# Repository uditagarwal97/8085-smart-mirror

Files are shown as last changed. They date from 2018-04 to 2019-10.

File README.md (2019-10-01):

View this project on [CADLAB.io](https://cadlab.io/node/885). 

# 8085-smart-mirror
Open source project which aims at making a smart mirror using Intel 8085 with esp8266 as wifi interface.

# Project Abstract
Our smart mirror won’t just say you’re the prettiest of them all. It will also tell you the temperature, daily tasks(to-do list), weather outside, upcoming calendar appointments, and more. Encapsulated within a wooden frame, it will consist of a two-way mirror with an electronic display and wifi module behind the mirror. In form of widgets, it deploys various multi-colour LED's accompanied with stencils to form an iconic indicator for various weather conditions.

An essential part of modern interior designing ideas is the use of mirrors. Long gong are the days, when mirror is just used to see your face. Now, Mirrors being an integral part of every household are now used to provide glamorous user-interface for a variety of smart products. Our project, 8085 based smart mirror is an attempt to intermingle our modern luxury with a so called 'obsolete' Intel's microprocessor 8085. 

Main objective of our work is to keep the user updated with his To-Do list, which was once entered by the user, stored securely on a reliable cloud database. With our Smart Mirror android application interface, user can smoothly update the data, with his location (required for weather) along with the SSID and password of the wireless interface, being used for data exchange purpose.
Along with this, weather forecast along with temperature is displayed for user's convenience.

Please find the project related documenttaion files in the docs directory and the associated YouTube video can be found [here](https://www.youtube.com/watch?v=hadKsCXobCI).

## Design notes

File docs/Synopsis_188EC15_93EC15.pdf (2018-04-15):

# 8085 based Smart Mirror

### Manoj sahu 93EC15 Udit kumar agarwal 188EC15

### Feb 2, 2018

## Synopsis

Our smart mirror wont just say youre the prettiest of them all. It will also tell you the time, daily tasks(to-do list), weather outside, upcoming calendar appointments, and more. Encapsulated within a wooden frame, it will consist of a two-way mirror with an electronic display and wifi module behind the mirror. In form of widgets, it deploys various multi-colour leds accompanied with stencils to form an iconic indicator for various weather conditions, pollution level etc. Along with it, there will be a 4 digit SSD which can be used to display time as well as temperature(in both centigrade and Fahrenheit format), in close proximity of user.

Keywords: 8085, Microprocessor, Assembly language, Two way mirror, esp8266

Category: Application based project

## 1. Motivation

Designing a micro processor 1 based system does involves thorough knowledge of prim-

itive yet pedagogically important computer architectures. Designing a complete embedded hardware project right from scratch imparts basic knowledge of advanced digital blocks used today in various micro controllers. Our project Smart mirror, presents an enthralling blend of science fiction with reality.

## 2. Justification

Nowadays, implementation of smart mirrors includes using high end processors like in raspberry pi and other single board computers. Using a cheap microprocessor like 8085 for recreating smart mirror, justifies it’s processing power. Moreover, Mirrors are an essential parts of every room, using it to display important information along with To-Do list sounds to be an interesting and a useful idea.

## 3. Brief description

It deploys a two way mirror to display multitude of necessary information in close proximity of user. Information to be displayed can be manipulated via an android application using wifi interface.

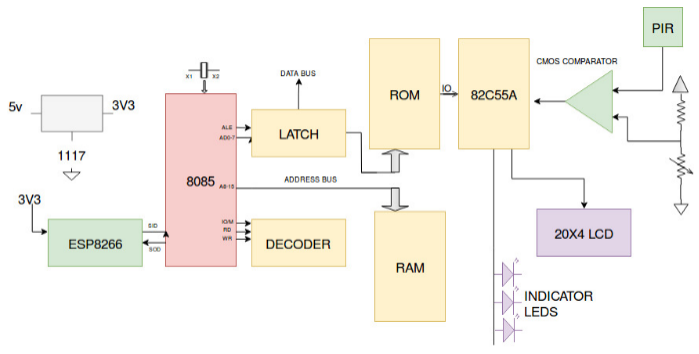
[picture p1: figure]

1here, Intel 8085

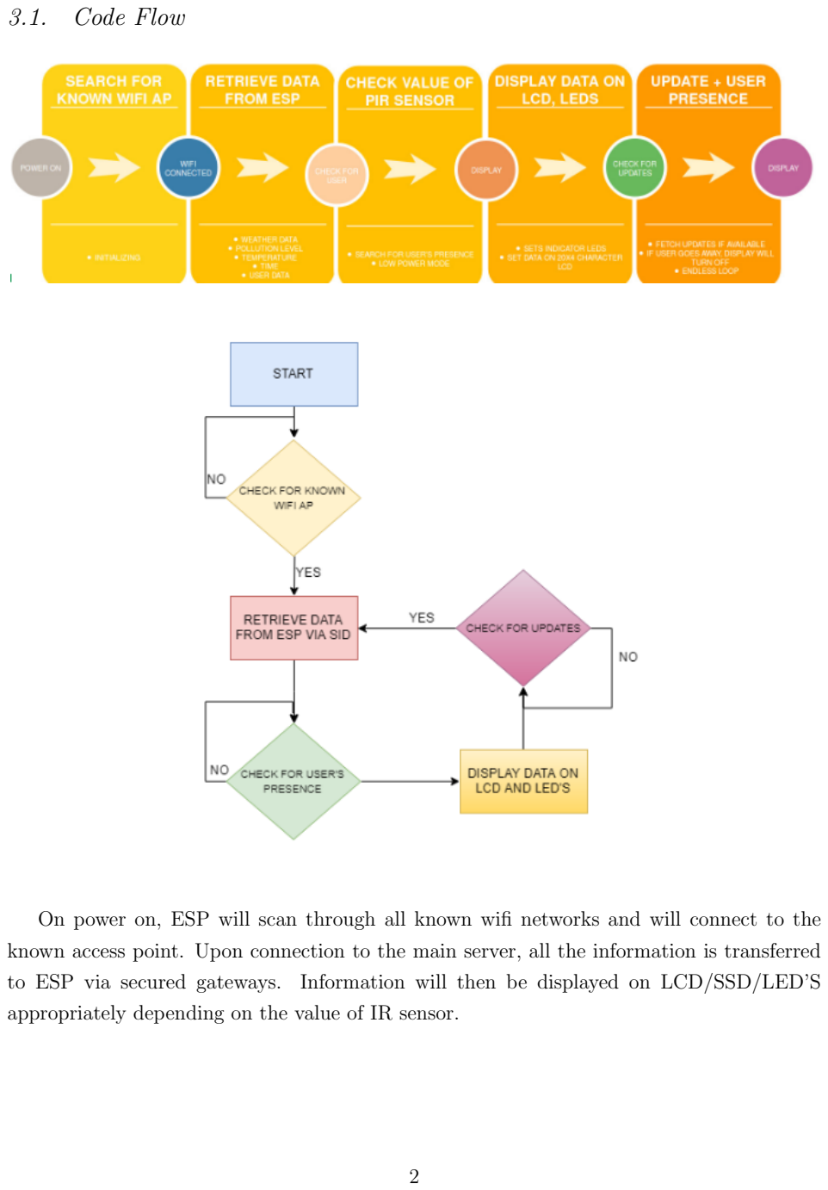
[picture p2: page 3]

### 3.1. Code Flow

On power on, ESP will scan through all known wifi networks and will connect to the known access point. Upon connection to the main server, all the information is transferred to ESP via secured gateways. Information will then be displayed on LCD/SSD/LED’S

appropriately depending on the value of IR sensor.

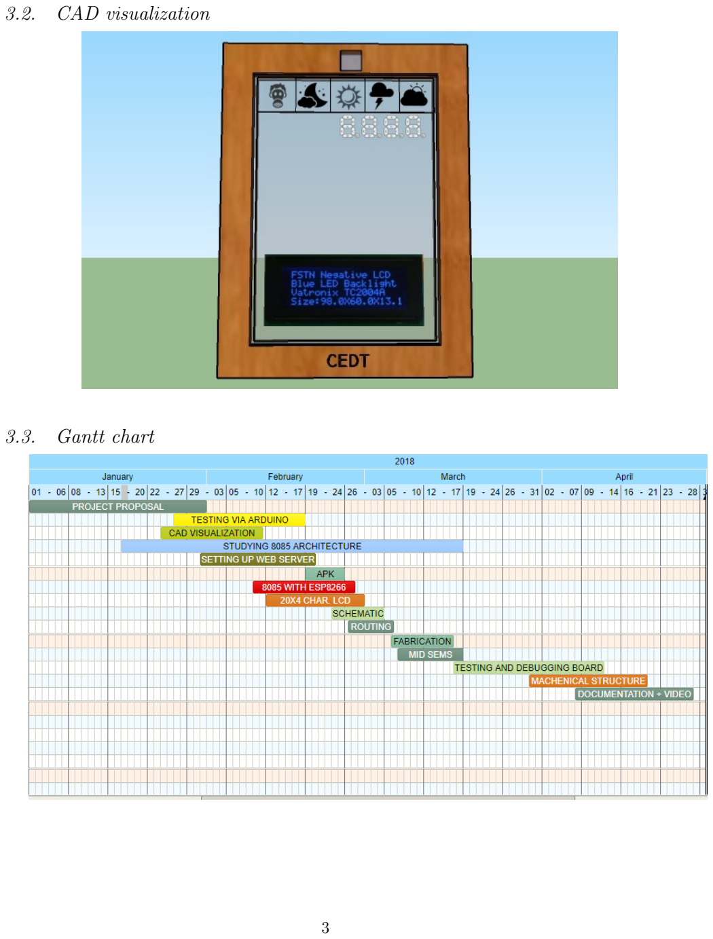
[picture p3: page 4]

### 3.2. CAD visualization

### 3.3. Gantt chart

## 4. Bill of Materials

Following are the expected materials required for the project:

S.No | Item | Quantity | Description
1 | 8085A | 1 | Microprocessor
2 | EEPROM | 1 | 32Kb ROM
3 | RAM | 1 | 32Kb RAM
4 | ESP8266 | 1 | Wifi module
5 | LM1117 | 1 | 3V3 regulator for ESP
6 | 74HC138 | 1 | 3X8 DECODER
7 | 74HCT04 | 1 | 6 not gate IC
8 | 74HCT573 | 1 | * bit D latch
9 | 82C55A | 1 | CMOS PPI
10 | 20X4 Character LCD | 1 | LCD
11 | Two way mirror | 1 | -
12 | PIR sensor | 1 | HCSR501
13 | 4 DIGIT SSD | 1 | Common cathode

## 5. References

- Microprocessor programming ,architecture and application with 8085 by Ramesh Goankar
- https://www.makeuseof.com/tag/6-best-raspberry-pi-smart-mirror-projects-weve-seenfar/
- https://hackaday.com/2016/04/27/smart-mirror-reflects-hacker/
- https://hackaday.com/2016/02/28/79-smart-mirror-uses-raspberry-pi/

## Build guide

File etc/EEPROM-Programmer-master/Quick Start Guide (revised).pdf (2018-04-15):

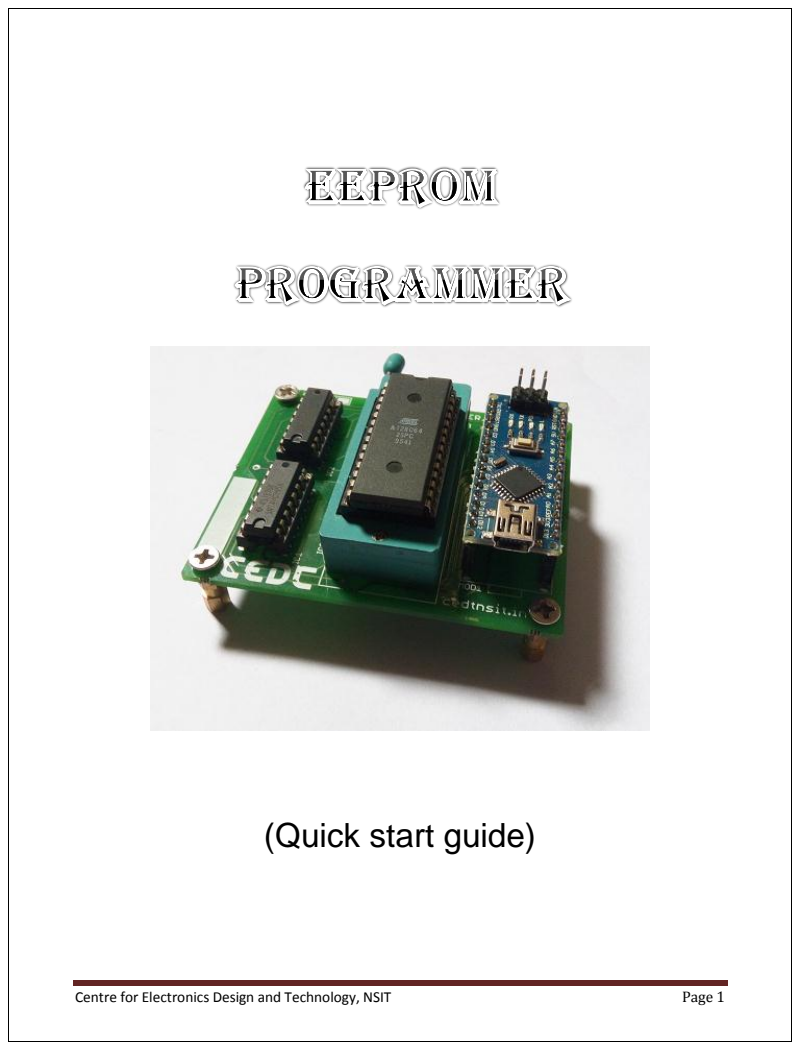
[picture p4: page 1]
Centre for Electronics Design and Technology, NSIT; Page 1

(Quick start guide)

# Table of Contents

S. No. Title | Page
1. | Introduction | 3
2. | Kit Contents | 4
3. | Soldering | 5
4. | Software toolchain | 7
5. | Operating Instructions | 11
6. | Troubleshooting | 16

# Introduction

The EEPROM Programmer is an Arduino Nano based circuit that has the capability to load data onto Parallel EEPROMs AT28C256 (32KB) and AT28C64 (8KB). This was developed at the Centre for Electronics Design and Technology, NSIT under the guidance of Prof. Dhananjay V. Gadre and Nikhilesh Prasannakumar as an aid for the students of the course EC-316 in Netaji Subhas Institute of Technology, Delhi.

This document guides the user through the process of setting up the tool and using it.

All queries can be directed to Anshuman Mishra (cedt.eepromprogrammer@gmail.com)

# Kit Contents

The kit provided to the user should have the following:

- 1 x EEPROM Programmer PCB
- 2 x IC Socket 16-pin DIP pitch 2.54mm, row spacing 0.3” (7.62mm)
( http://www.digikey.com/product-detail/en/assmann-wsw-components/A16-LC-TT/AE9992-ND/821746 (http://www.digikey.com/product-detail/en/assmann-wsw-components/A16-LC-TT/AE9992-ND/821746) )
- 1 x IC Socket 28-pin DIP pitch 2.54mm, row spacing 0.6” (15.24mm)
( http://www.digikey.com/product-detail/en/assmann-wsw-components/A28-LC-TT/AE10004-ND/821758 (http://www.digikey.com/product-detail/en/assmann-wsw-components/A28-LC-TT/AE10004-ND/821758) )
- 3 x 0.1µF 0805 SMD Capacitor (Ceramic)
( http://www.digikey.com/product-detail/en/samsung-electro-mechanics-americainc/CL21F104ZBCNNNC/1276-1007-2-ND/3886665 )
- 2 x Female Socket 40 Pins Single Row Straight 2.54mm Pitch

Additional items required and not provided in the kit:

- 1 x Arduino Nano
- 2 x 74HC595* (16-PDIP) Shift Register
( http://www.digikey.com/product-detail/en/texasinstruments/CD74HC595EE4/CD74HC595EE4-ND/1507397 (http://www.digikey.com/product-detail/en/texas-instruments/CD74HC595EE4/CD74HC595EE4-ND/1507397) )
- 1 x Parallel EEPROM (AT28C256 or AT28C64)

Note: The user can replace the 28-pin 0.6” IC socket with a 28-pin 0.6” ZIF socket. The ZIF socket is not provided in the kit and will have to be arranged by the user himself if he so wishes to.

*Recommended. Other families may also be compatible.

# Soldering

The kit provided to you needs to be soldered properly in order to be useful. Proper soldering would play a major role in the operation of the Programmer later. Hence special care should be taken at this stage to avoid troubleshooting issues later.

What tools are needed for soldering the board?

- The kit, containing the PCB and the required components
- A soldering station
- Soldering sponge
- Water spray
- Tweezers
- Solder

What precautions are needed before starting soldering?

a) The workspace should be cleared of all unnecessary material
b) There should be no entanglement of wires
c) The soldering sponge should be just wet. Neither too much nor too little.
d) Gather all the required tools and materials within easy reach

Soldering the components

The positions of various components have been marked on the PCB. The order of soldering the components should be

1. 0.1µF Capacitors (SMD)
2. 28-pin Wide IC socket (for the AT28C256 or AT28C64)
3. 16-pin IC sockets (for the shift registers)
4. 2 strips of Female headers (for the Arduino Nano)

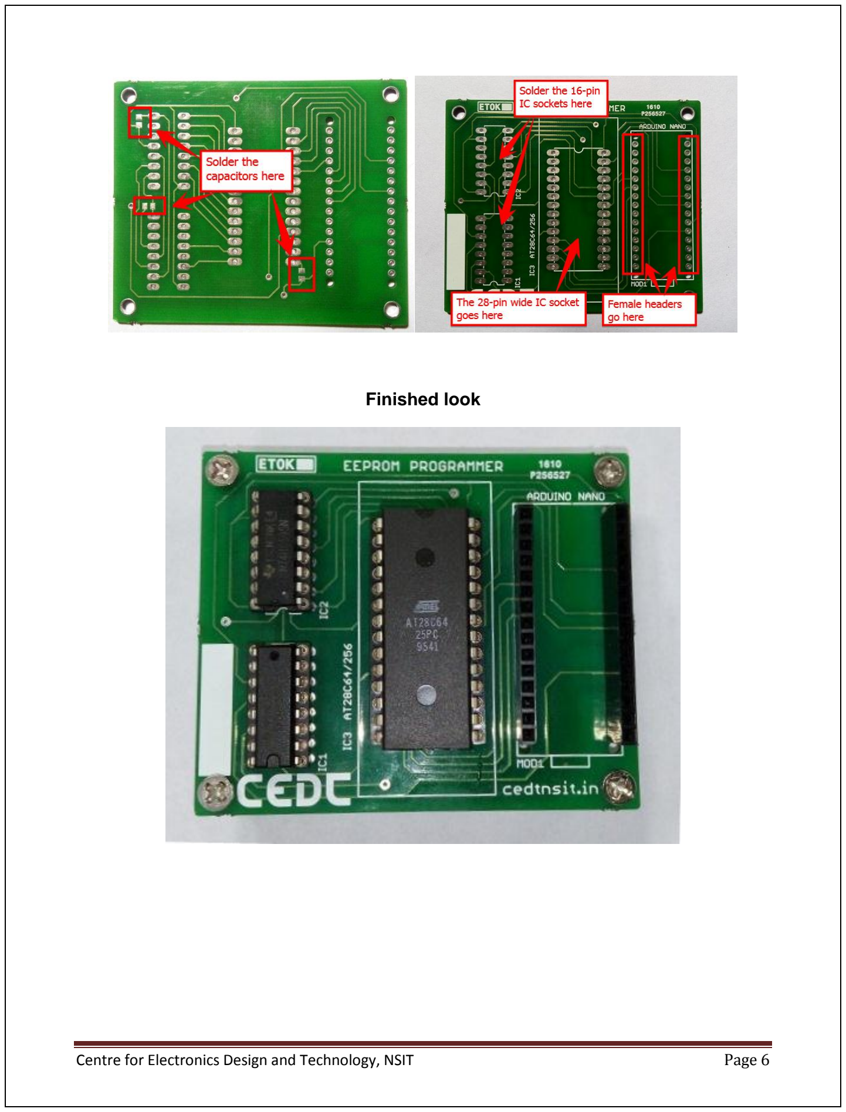
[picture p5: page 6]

Finished look

# Software Toolchain

Pre requisites

- Java JRE 1.8.0 or later
- 8085 Simulator IDE

Steps

### 1. Go to www.github.com/anshuman94/EEPROM-Programmer and Click on the

Download ZIP button

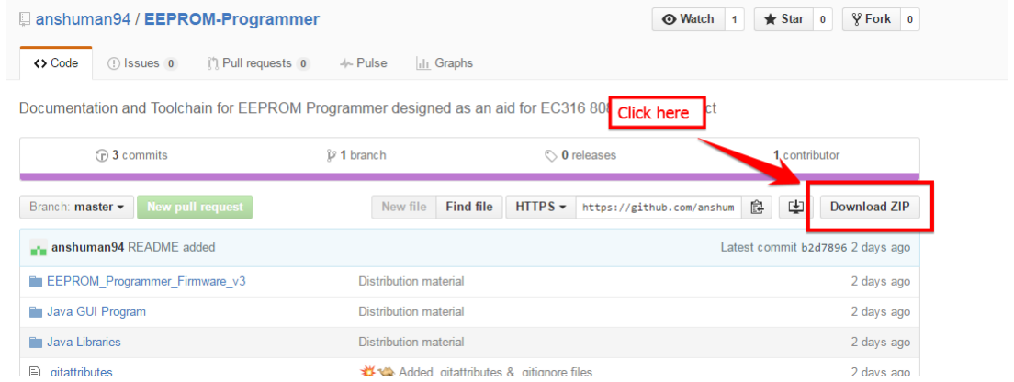
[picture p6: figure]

This will download a zip file containing all the requisite files.

### 2. Go to the JAVA Libraries folder and copy the rxtxSerial.dll and rxtxParallel.dll

files (If you are on a 64-bit machine, copy the rxtxSerial64.dll and rxtxParallel64.dll files and remove the 64 suffix from the file names)

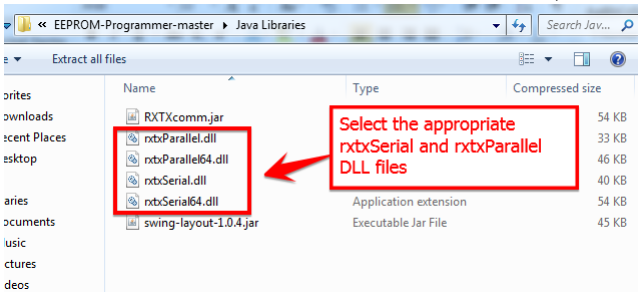
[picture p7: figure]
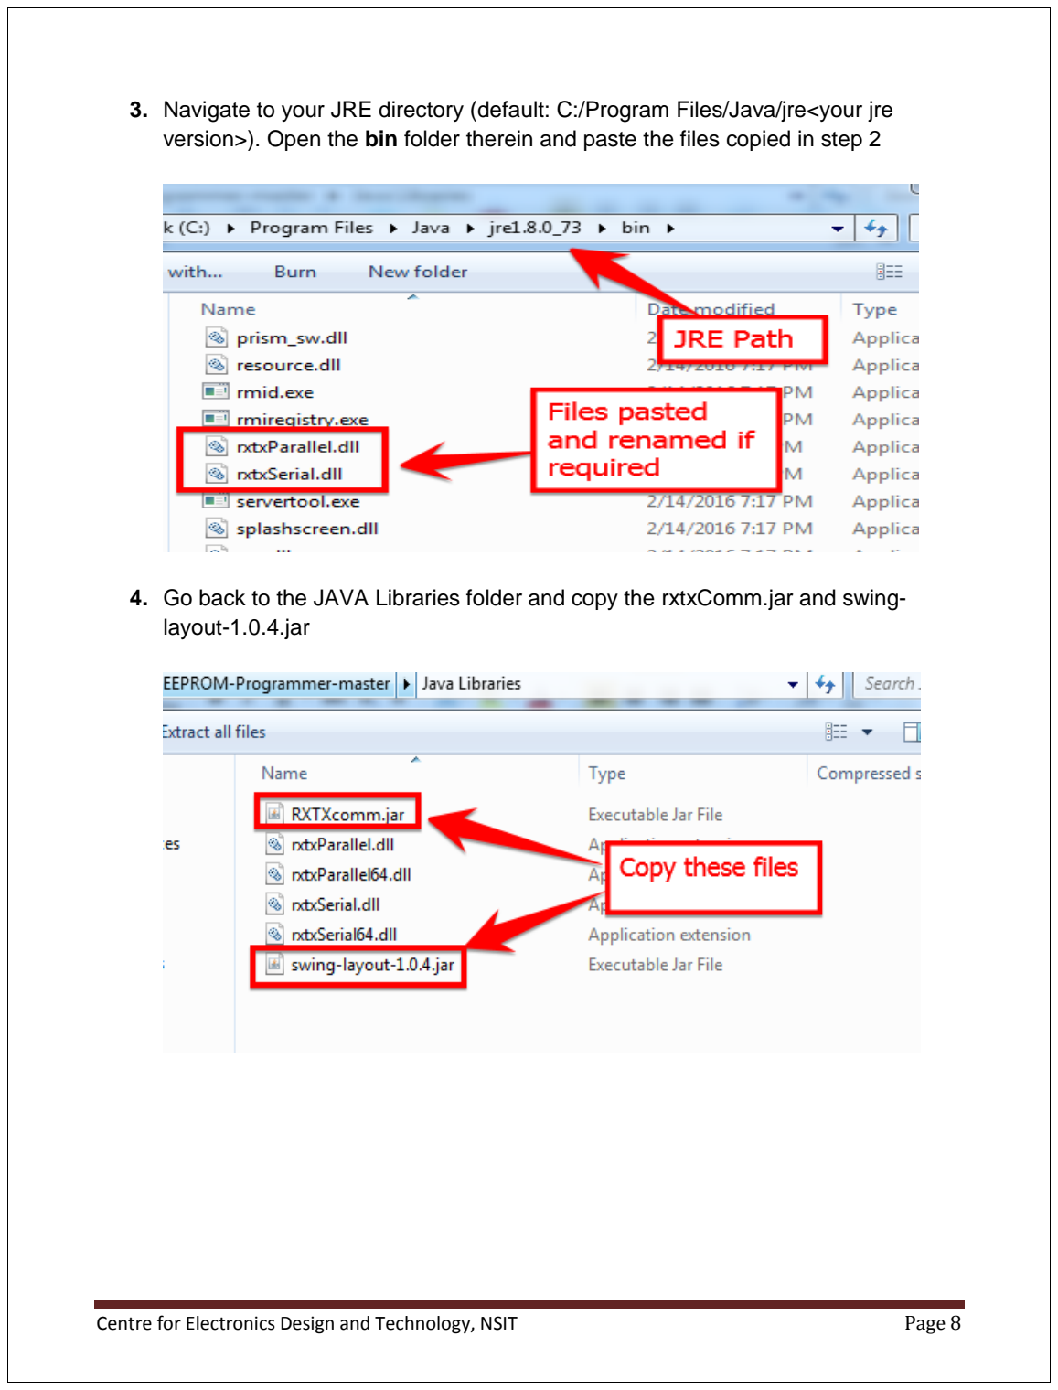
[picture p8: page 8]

### 3. Navigate to your JRE directory (default: C:/Program Files/Java/jre<your jre

version>). Open the bin folder therein and paste the files copied in step 2

### 4. Go back to the JAVA Libraries folder and copy the rxtxComm.jar and swing-

layout-1.0.4.jar

### 5. Navigate to your JRE directory (default: C:/Program Files/Java/jre<your jre

version>). Open the ext sub folder in lib folder and paste the files copied in step 4

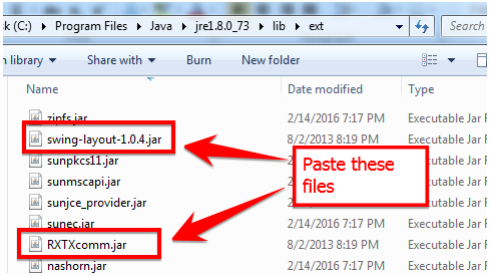
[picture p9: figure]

Now your System is ready to interface with the hardware.

6. Go back to the downloaded folder and open the EEPROM Programmer.jar in the JAVA GUI Program folder

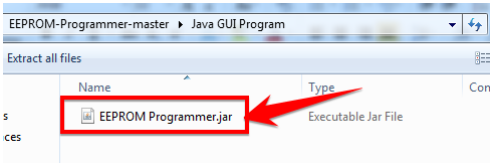
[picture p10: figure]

This will open up Graphical Interface to be used to burn your programs onto the EEPROM.

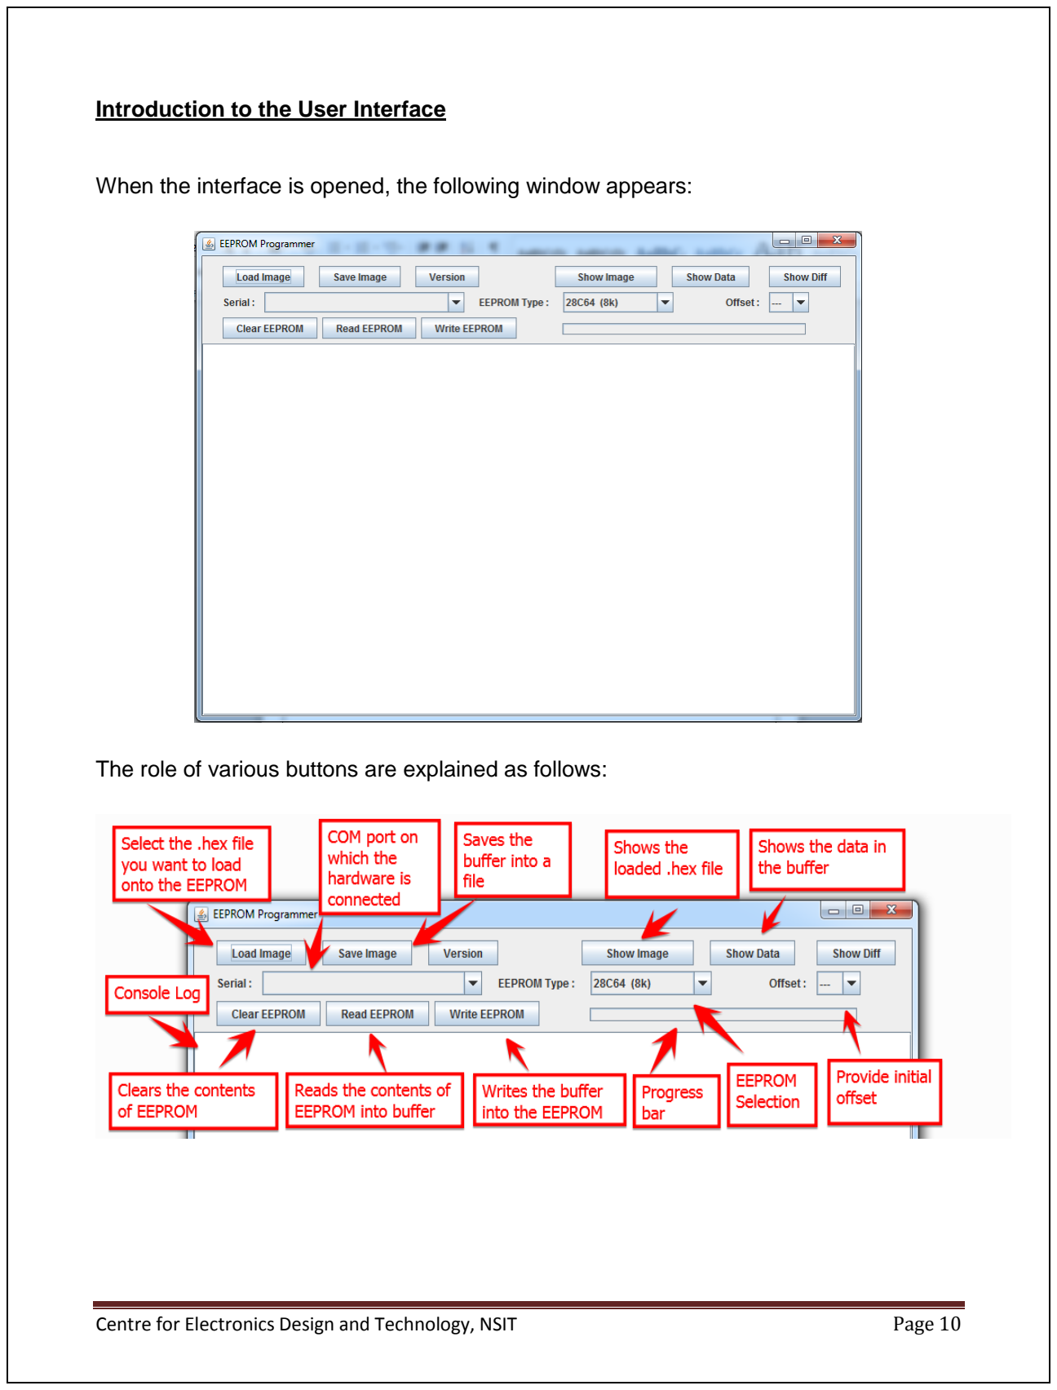
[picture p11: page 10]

Introduction to the User Interface

When the interface is opened, the following window appears:

The role of various buttons are explained as follows:

# Operating Instructions

First Steps

### 1. Connect your Arduino Nano to your computer and wait for the driver to install (if

required)

### 2. Open Device Manager and Note down the COM port on which your Arduino is

connected.

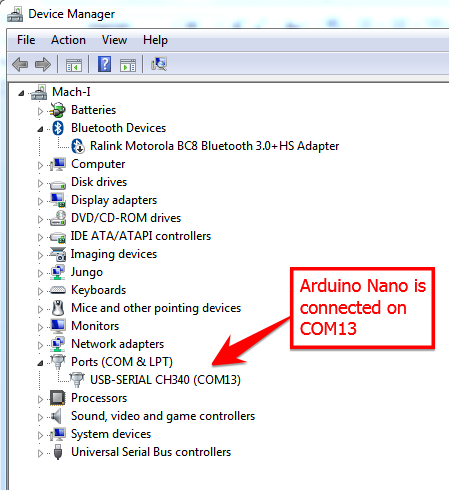
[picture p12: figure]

### 3. Go to the downloaded EEPROM-Programmer-

master/EEPROM_Programmer_Firmware_v3 folder

### 4. Open the sketch in Arduino IDE and upload the code to the connected Arduino

Nano.
5. Open the EEPROM Programmer.jar in the JAVA GUI Program folder.

### 6. From the list of shown COM ports, Select the one on which Arduino Nano is

connected (Important)

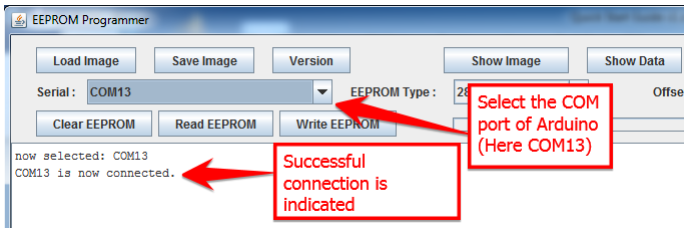
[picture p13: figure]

### 7. Select the type of EEPROM you want to program (Important)

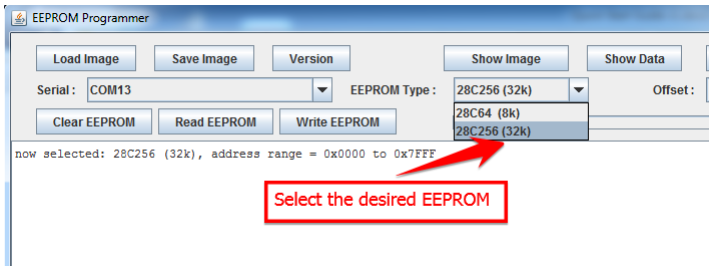
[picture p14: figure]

Now you are ready to burn your data onto the EEPROM. You can verify that you are set to go by clicking the Verify button. You should get the following output in console log:

### 8. Clearing the EEPROM

In order to clear the EEPROM; make sure that the appropriate COM Port and the EEPROM is selected.

Once that is done, Press the Clear EEPROM button and wait till the process is completed (It will be shown in the Console Log)

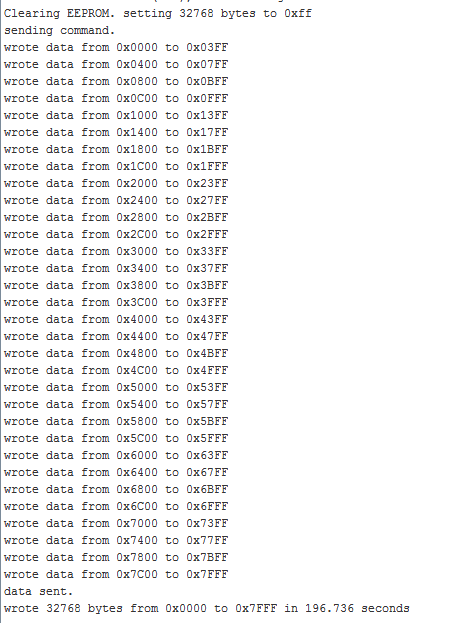
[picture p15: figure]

9. Writing a program to the EEPROM
a. Select the file you want to load onto the EEPROM by clicking the Load Image button
b. Select your file and Click Open

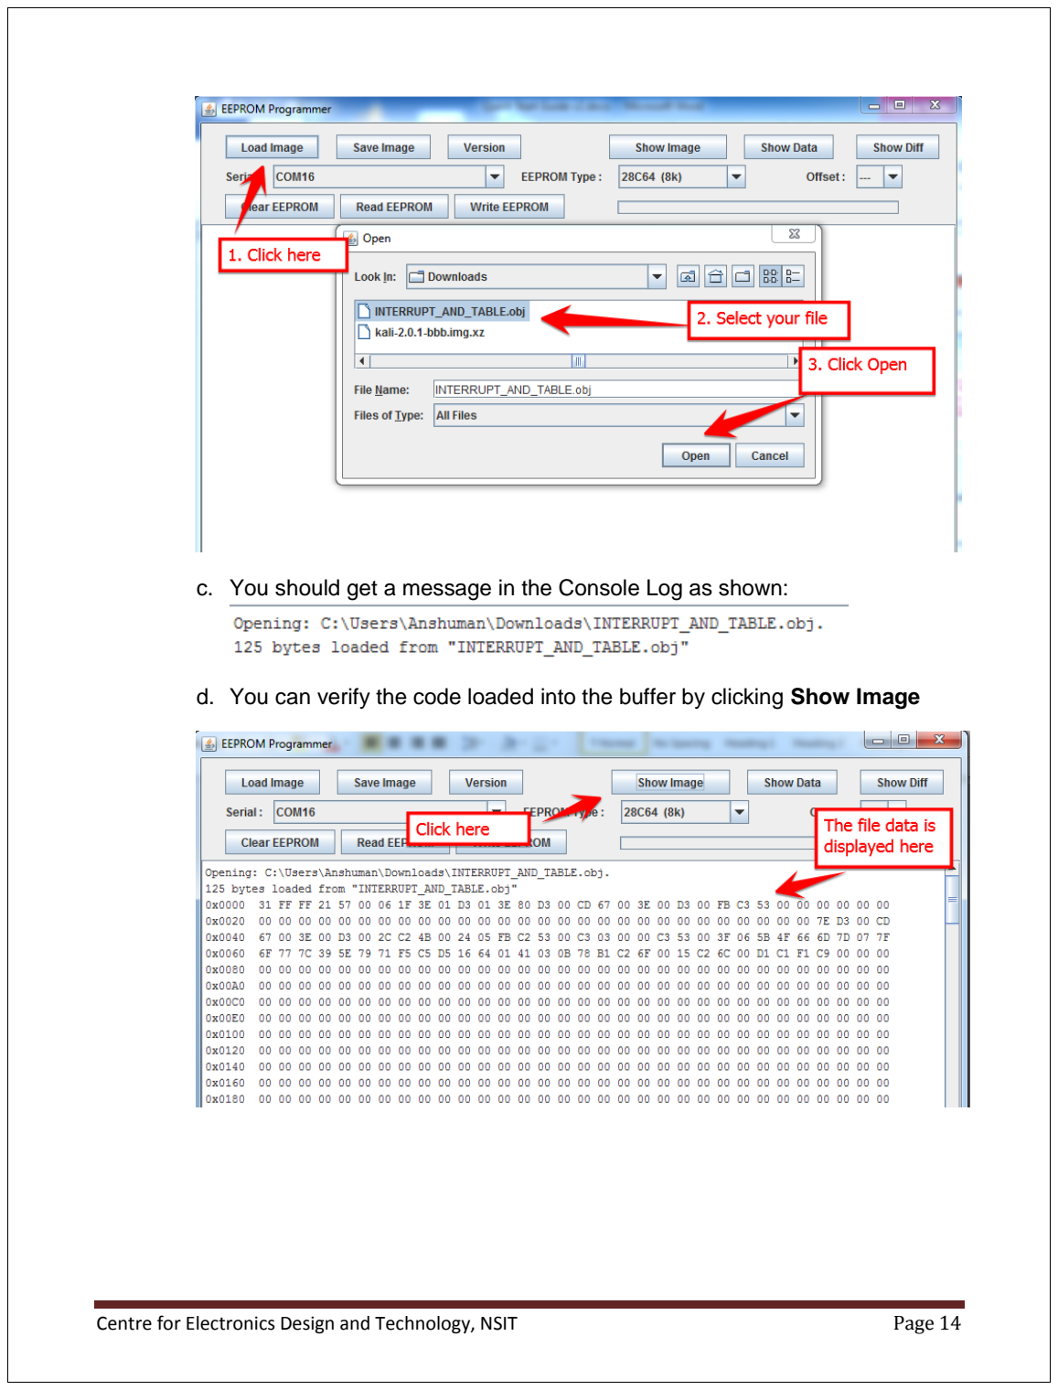
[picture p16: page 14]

c. You should get a message in the Console Log as shown:
d. You can verify the code loaded into the buffer by clicking Show Image e. Now all that’s left is to burn this image to the EEPROM. You can do this by clicking the Write EEPROM button.

10.Read Data from an EEPROM

Sometimes, you might want to read the EEPROM to view its contents or to back up the contents. You can do this by the following steps:

a. Make sure the EEPROM Programmer is connected, COM port is selected and the correct EEPROM is selected.
b. Click the Read EEPROM button and wait till the operation is completed. (You will be notified in the console)
c. You can view the contents by clicking the Show Data button.

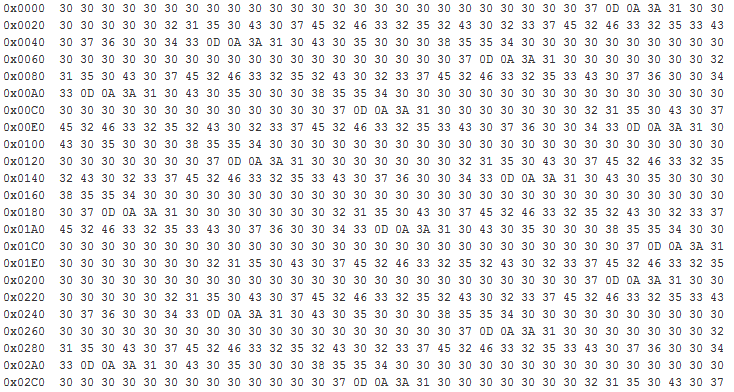
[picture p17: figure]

# Troubleshooting

Q1. I cannot find JRE folder. What do I do?

It might very well be possible that JRE is not installed on your system. You can verify it by going to Command Prompt (Windows) and type java –version and press Enter. If you get an error, your system does not have the JRE, so you need to download and install the Java Runtime Environment (SE).

Q2. I tried to execute the program but it doesn’t seem to run?

It is possible that you copied the wrong libraries (as in used 32-bit files on a 64-bit machine or vice versa) Do check and try to execute. Make sure you have renamed the DLL files (rxtxSerial and rxtxParallel) in case of 64-bit machines.

You can also try to check for errors by executing the program via the command prompt using the command java jar <Name of Program>

If you still face a problem, drop a mail at cedt.eepromprogrammer@gmail.com

Q3. I was able to open the program but it does not detect my hardware?

- Disconnect the hardware
- Close the program
- Connect the hardware and wait till it shows up in the Device Manager
- Open the program now
- Select the COM port specifically.
- Now make sure you specifically select the EEPROM you are programming (especially if you are programming the AT28C256 32KB EEPROM)
- You are good to go. You can verify by clicking the Version button.

Q4. Data didn’t change when I burned my program onto the EEPROM?

Make sure you read the EEPROM again and only then Show the data to get the updated values.

Any unanswered issues can be directed at Anshuman Mishra (cedt.eepromprogrammer@gmail.com)

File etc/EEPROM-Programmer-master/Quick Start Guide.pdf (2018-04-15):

Centre for Electronics Design and Technology, NSIT; Page 1

(Quick start guide)

# Table of Contents

S. No. Title | Page
1. | Introduction | 3
2. | Kit Contents | 4
3. | Soldering | 5
4. | Software toolchain | 7
5. | Operating Instructions | 11
6. | Troubleshooting | 16

# Introduction

The EEPROM Programmer is an Arduino Nano based circuit that has the capability to load data onto Parallel EEPROMs AT28C256 (32KB) and AT28C64 (8KB). This was developed at the Centre for Electronics Design and Technology, NSIT under the guidance of Prof. Dhananjay V. Gadre and Nikhilesh Prasannakumar as an aid for the students of the course EC-316 in Netaji Subhas Institute of Technology, Delhi.

This document guides the user through the process of setting up the tool and using it.

All queries can be directed to Anshuman Mishra (cedt.eepromprogrammer@gmail.com)

# Kit Contents

The kit provided to the user should have the following:

- 1 x EEPROM Programmer PCB
- 2 x IC Socket 16-pin DIP pitch 2.54mm, row spacing 0.3” (7.62mm)
( http://www.digikey.com/product-detail/en/assmann-wsw-components/A16-LC-TT/AE9992-ND/821746 (http://www.digikey.com/product-detail/en/assmann-wsw-components/A16-LC-TT/AE9992-ND/821746) )
- 1 x IC Socket 28-pin DIP pitch 2.54mm, row spacing 0.6” (15.24mm)
( http://www.digikey.com/product-detail/en/assmann-wsw-components/A28-LC-TT/AE10004-ND/821758 (http://www.digikey.com/product-detail/en/assmann-wsw-components/A28-LC-TT/AE10004-ND/821758) )
- 3 x 0.1µF 0805 SMD Capacitor (Ceramic)
( http://www.digikey.com/product-detail/en/samsung-electro-mechanics-americainc/CL21F104ZBCNNNC/1276-1007-2-ND/3886665 )
- 2 x Female Socket 40 Pins Single Row Straight 2.54mm Pitch

Additional items required and not provided in the kit:

- 1 x Arduino Nano
- 2 x 74HC595* (16-PDIP) Shift Register
( http://www.digikey.com/product-detail/en/texasinstruments/CD74HC595EE4/CD74HC595EE4-ND/1507397 (http://www.digikey.com/product-detail/en/texas-instruments/CD74HC595EE4/CD74HC595EE4-ND/1507397) )
- 1 x Parallel EEPROM (AT28C256 or AT28C64)

Note: The user can replace the 28-pin 0.6” IC socket with a 28-pin 0.6” ZIF socket. The ZIF socket is not provided in the kit and will have to be arranged by the user himself if he so wishes to.

*Recommended. Other families may also be compatible.

# Soldering

The kit provided to you needs to be soldered properly in order to be useful. Proper soldering would play a major role in the operation of the Programmer later. Hence special care should be taken at this stage to avoid troubleshooting issues later.

What tools are needed for soldering the board?

- The kit, containing the PCB and the required components
- A soldering station
- Soldering sponge
- Water spray
- Tweezers
- Solder

What precautions are needed before starting soldering?

a) The workspace should be cleared of all unnecessary material
b) There should be no entanglement of wires
c) The soldering sponge should be just wet. Neither too much nor too little.
d) Gather all the required tools and materials within easy reach

Soldering the components

The positions of various components have been marked on the PCB. The order of soldering the components should be

1. 0.1µF Capacitors (SMD)
2. 28-pin Wide IC socket (for the AT28C256 or AT28C64)
3. 16-pin IC sockets (for the shift registers)
4. 2 strips of Female headers (for the Arduino Nano)


Finished look

# Software Toolchain

Pre requisites

- Java JRE 1.8.0 or later
- 8085 Simulator IDE

Steps

### 1. Go to www.github.com/anshuman94/EEPROM-Programmer and Click on the

Download ZIP button


This will download a zip file containing all the requisite files.

### 2. Go to the JAVA Libraries folder and copy the rxtxSerial.dll and rxtxParallel.dll

files (If you are on a 64-bit machine, copy the rxtxSerial64.dll and rxtxParallel64.dll files)

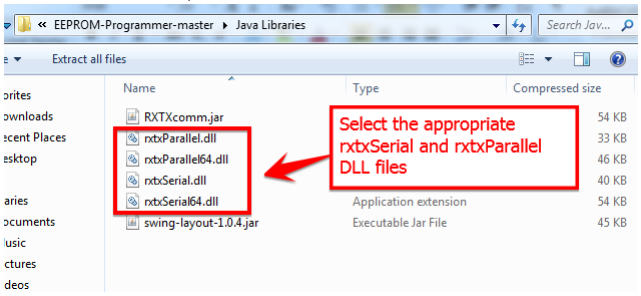
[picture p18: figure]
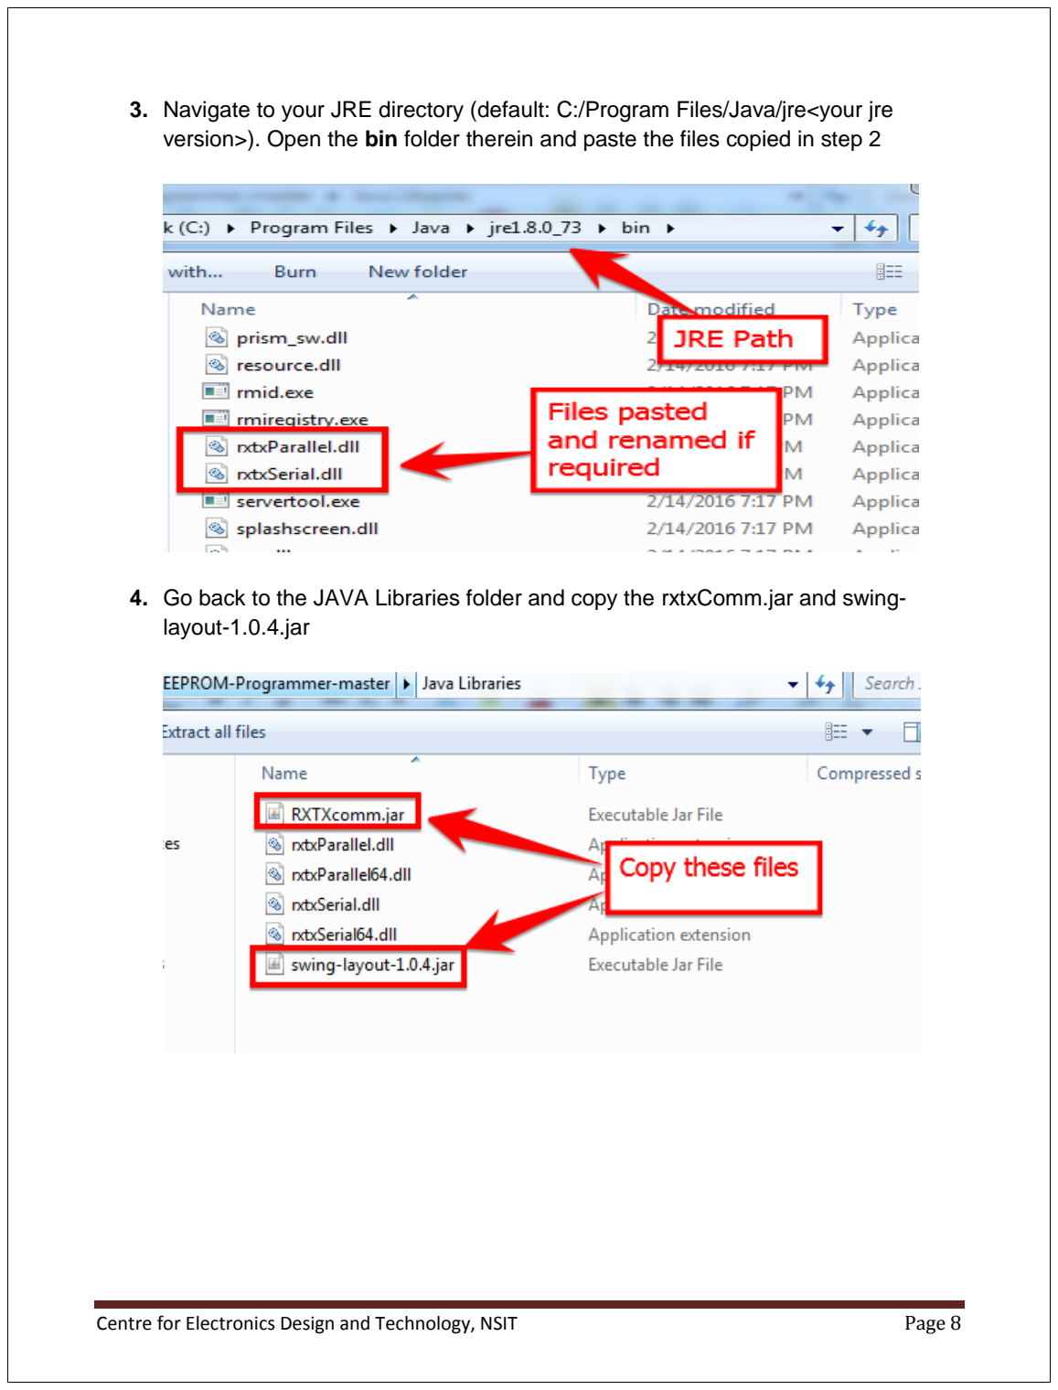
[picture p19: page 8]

### 3. Navigate to your JRE directory (default: C:/Program Files/Java/jre<your jre

version>). Open the bin folder therein and paste the files copied in step 2

### 4. Go back to the JAVA Libraries folder and copy the rxtxComm.jar and swing-

layout-1.0.4.jar

### 5. Navigate to your JRE directory (default: C:/Program Files/Java/jre<your jre

version>). Open the lib/ext folder therein and paste the files copied in step 4


Now your System is ready to interface with the hardware.

6. Go back to the downloaded folder and open the EEPROM Programmer.jar in the JAVA GUI Program folder


This will open up Graphical Interface to be used to burn your programs onto the EEPROM.


Introduction to the User Interface

When the interface is opened, the following window appears:

The role of various buttons are explained as follows:

# Operating Instructions

First Steps

### 1. Connect your Arduino Nano to your computer and wait for the driver to install (if

required)

### 2. Open Device Manager and Note down the COM port on which your Arduino is

connected.


### 3. Go to the downloaded EEPROM-Programmer-

master/EEPROM_Programmer_Firmware_v3 folder

### 4. Open the sketch in Arduino IDE and upload the code to the connected Arduino

Nano.
5. Open the EEPROM Programmer.jar in the JAVA GUI Program folder.

### 6. From the list of shown COM ports, Select the one on which Arduino Nano is

connected (Important)


### 7. Select the type of EEPROM you want to program (Important)


Now you are ready to burn your data onto the EEPROM. You can verify that you are set to go by clicking the Verify button. You should get the following output in console log:

### 8. Clearing the EEPROM

In order to clear the EEPROM; make sure that the appropriate COM Port and the EEPROM is selected.

Once that is done, Press the Clear EEPROM button and wait till the process is completed (It will be shown in the Console Log)


9. Writing a program to the EEPROM
a. Select the file you want to load onto the EEPROM by clicking the Load Image button
b. Select your file and Click Open


c. You should get a message in the Console Log as shown:
d. You can verify the code loaded into the buffer by clicking Show Image e. Now all that’s left is to burn this image to the EEPROM. You can do this by clicking the Write EEPROM button.

10.Read Data from an EEPROM

Sometimes, you might want to read the EEPROM to view its contents or to back up the contents. You can do this by the following steps:

a. Make sure the EEPROM Programmer is connected, COM port is selected and the correct EEPROM is selected.
b. Click the Read EEPROM button and wait till the operation is completed. (You will be notified in the console)
c. You can view the contents by clicking the Show Data button.


# Troubleshooting

Q1. I cannot find JRE folder. What do I do?

It might very well be possible that JRE is not installed on your system. You can verify it by going to Command Prompt (Windows) and type java –version and press Enter. If you get an error, your system does not have the JRE, so you need to download and install the Java Runtime Environment (SE).

Q2. I tried to execute the program but it doesn’t seem to run?

It is possible that you copied the wrong libraries (as in used 32-bit files on a 64-bit machine or vice versa) Do check and try to execute. You can also try to check for errors by executing the program via the command prompt using the command java jar <Name of Program>

If you still face a problem, drop a mail at cedt.eepromprogrammer@gmail.com

Q3. I was able to open the program but it does not detect my hardware?

- Disconnect the hardware
- Close the program
- Connect the hardware and wait till it shows up in the Device Manager
- Open the program now
- Select the COM port specifically.
- Now make sure you specifically select the EEPROM you are programming (especially if you are programming the AT28C256 32KB EEPROM)
- You are good to go. You can verify by clicking the Version button.

Q4. Data didn’t change when I burned my program onto the EEPROM?

Make sure you read the EEPROM again and only then Show the data to get the updated values.

Any unanswered issues can be directed at Anshuman Mishra (cedt.eepromprogrammer@gmail.com)

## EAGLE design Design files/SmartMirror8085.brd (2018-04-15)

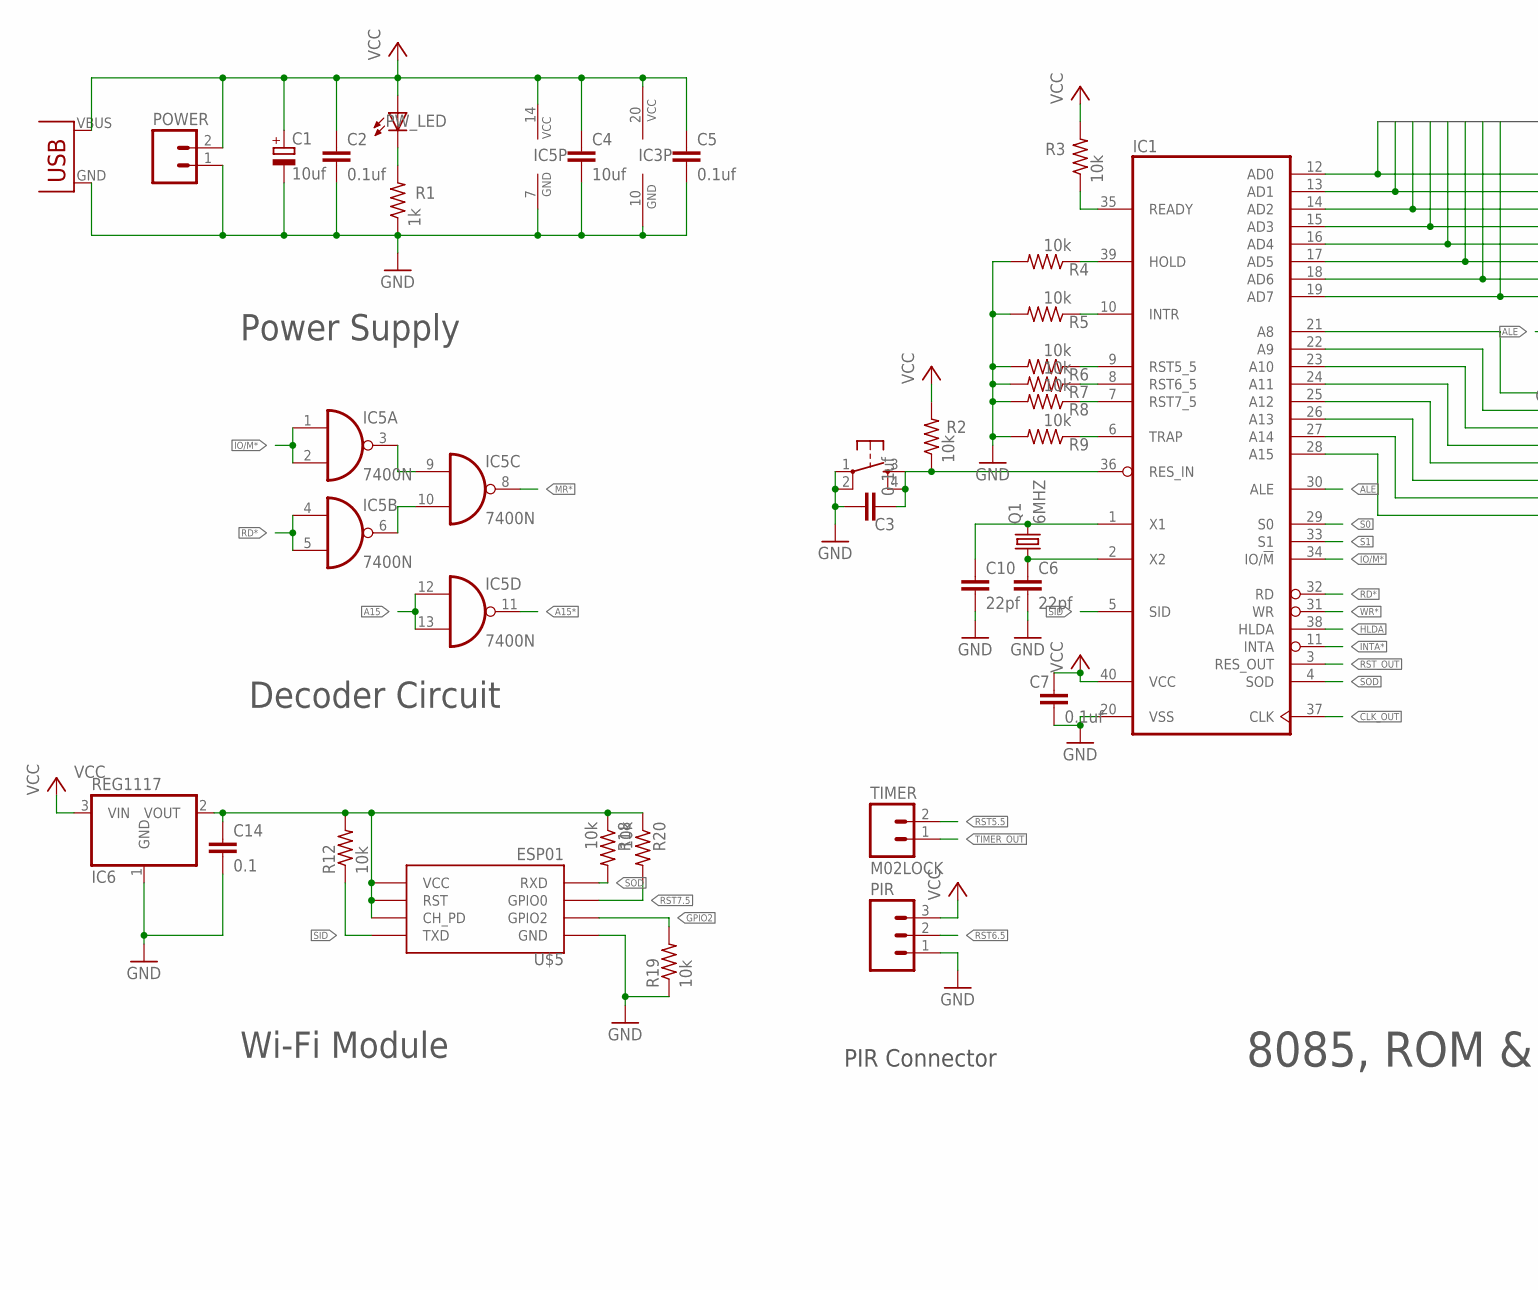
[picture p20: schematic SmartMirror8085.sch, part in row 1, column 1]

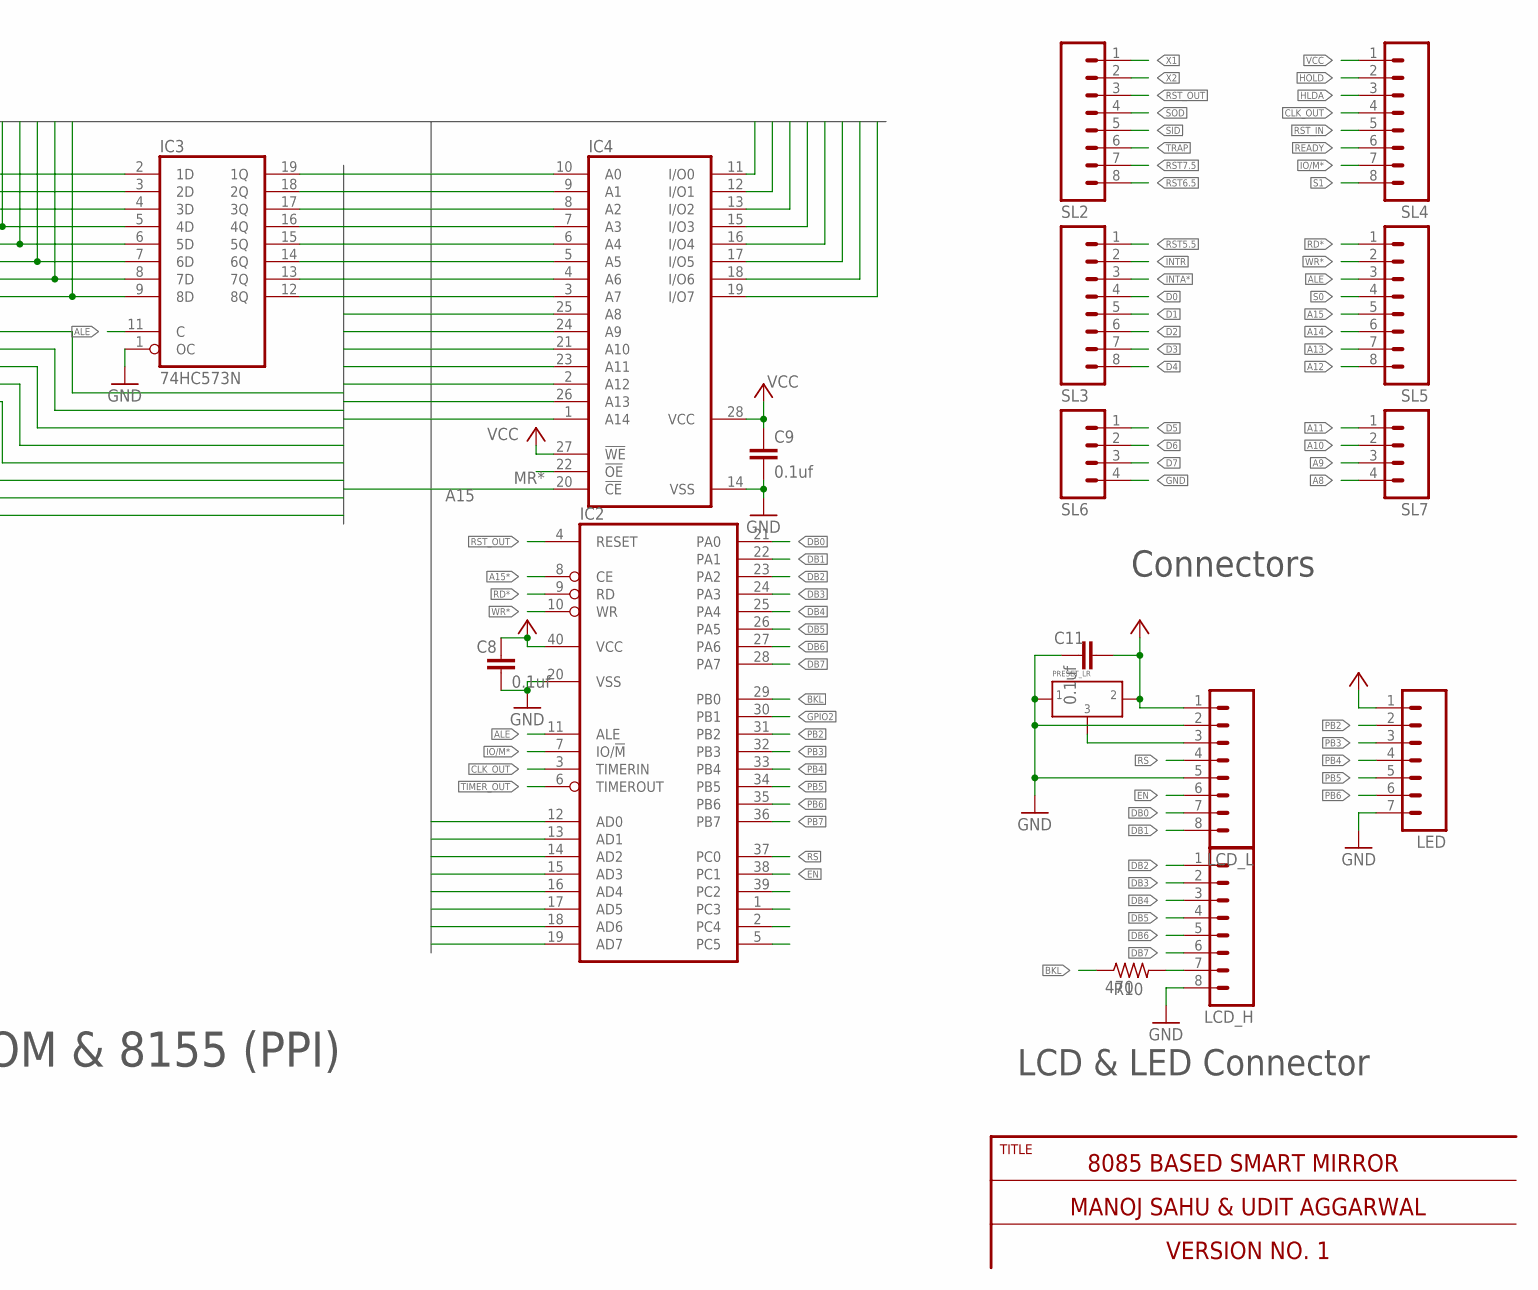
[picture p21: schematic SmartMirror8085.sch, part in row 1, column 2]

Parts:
C1: 10uf; E5-8,5
C2, C3, C5, C7, C8, C9, C11: 0.1uf; C025-024X044
C4: 10uf; C025-024X044
C6, C10: 22pf; C025-024X044
C14: 0.1; C025-024X044
IC1: 8085; DIL40
IC2: 8155; DIL40
IC3: 74HC573N; DIL20
IC4: 58C256P; DIL28-6
IC5: 7400N; DIL14
IC6: REG1117; SOT223
LCD_H: M08; 08P
LCD_L: M08; 08P
LED: M07; 07P
PIR: M03; 03P
POWER: M02; 02P
PW_LED: LED3MM
Q1: 6MHZ; HC49US
R1: 1k; 0207/7
R2, R3, R4, R5, R6, R7, R8, R9, R12, R18, R19, R20: 10k; 0207/7
R10: 470; 0207/7
RESET: OMRON_SWITCH_10-XX; B3F-10XX
SL2, SL3, SL4, SL5: M08; 08P
SL6, SL7: M04; 04P
TIMER: M02LOCK; 1X02_LOCK
U$2: USB(POWER)
U$3: PRESET_LR
U$5: ESP01

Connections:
3V3: C14.1, IC6.2 (VOUT), R12.2, R18.1, R20.1, U$5.CH_PD, U$5.RST, U$5.VCC
A0: IC3.19 (1Q), IC4.10 (A0)
A1: IC3.18 (2Q), IC4.9 (A1)
A2: IC3.17 (3Q), IC4.8 (A2)
A3: IC3.16 (4Q), IC4.7 (A3)
A4: IC3.15 (5Q), IC4.6 (A4)
A5: IC3.14 (6Q), IC4.5 (A5)
A6: IC3.13 (7Q), IC4.4 (A6)
A7: IC3.12 (8Q), IC4.3 (A7)
A8: IC1.21 (A8), IC4.25 (A8), SL7.4
A9: IC1.22 (A9), IC4.24 (A9), SL7.3
A10: IC1.23 (A10), IC4.21 (A10), SL7.2
A11: IC1.24 (A11), IC4.23 (A11), SL7.1
A12: IC1.25 (A12), IC4.2 (A12), SL5.8
A13: IC1.26 (A13), IC4.26 (A13), SL5.7
A14: IC1.27 (A14), IC4.1 (A14), SL5.6
A15: IC1.28 (A15), IC4.20 (!CE), IC5.12 (I0), IC5.13 (I1), SL5.5
A15*: IC2.8 (CE), IC5.11 (O)
ALE: IC1.30 (ALE), IC2.11 (ALE), IC3.11 (C), SL5.3
BKL: IC2.29 (PB0), R10.1
CLK_OUT: IC1.37 (CLK), IC2.3 (TIMERIN), SL4.4
D0: IC1.12 (AD0), IC2.12 (AD0), IC3.2 (1D), IC4.11 (I/O0), SL3.4
D1: IC1.13 (AD1), IC2.13 (AD1), IC3.3 (2D), IC4.12 (I/O1), SL3.5
D2: IC1.14 (AD2), IC2.14 (AD2), IC3.4 (3D), IC4.13 (I/O2), SL3.6
D3: IC1.15 (AD3), IC2.15 (AD3), IC3.5 (4D), IC4.15 (I/O3), SL3.7
D4: IC1.16 (AD4), IC2.16 (AD4), IC3.6 (5D), IC4.16 (I/O4), SL3.8
D5: IC1.17 (AD5), IC2.17 (AD5), IC3.7 (6D), IC4.17 (I/O5), SL6.1
D6: IC1.18 (AD6), IC2.18 (AD6), IC3.8 (7D), IC4.18 (I/O6), SL6.2
D7: IC1.19 (AD7), IC2.19 (AD7), IC3.9 (8D), IC4.19 (I/O7), SL6.3
DB0: IC2.21 (PA0), LCD_L.7
DB1: IC2.22 (PA1), LCD_L.8
DB2: IC2.23 (PA2), LCD_H.1
DB3: IC2.24 (PA3), LCD_H.2
DB4: IC2.25 (PA4), LCD_H.3
DB5: IC2.26 (PA5), LCD_H.4
DB6: IC2.27 (PA6), LCD_H.5
DB7: IC2.28 (PA7), LCD_H.6
EN: IC2.38 (PC1), LCD_L.6
GND: C1.-, C2.2, C3.1, C4.2, C5.2, C6.2, C7.2, C8.2, C9.2, C10.2, C11.2, C14.2, IC1.20 (VSS), IC2.20 (VSS), IC3.1 (OC), IC3.10 (GND), IC4.14 (VSS), IC5.7 (GND), IC6.1 (GND), LCD_H.8, LCD_L.2, LCD_L.5, LED.7, PIR.1, POWER.1, R1.1, R4.2, R5.2, R6.2, R7.2, R8.2, R9.2, R19.1, RESET.1, RESET.2 (P1), SL6.4, U$2.GND, U$3.P$1 (1), U$5.GND
GPIO2: IC2.30 (PB1), R19.2, U$5.GPIO2
HLDA: IC1.38 (HLDA), SL4.3
HOLD: IC1.39 (HOLD), R4.1, SL4.2
INTA*: IC1.11 (INTA), SL3.3
INTR: IC1.10 (INTR), R5.1, SL3.2
IO/M*: IC1.34 (IO/!M), IC2.7 (IO/!M), IC5.1 (I0), IC5.2 (I1), SL4.7
MR*: IC4.22 (!OE), IC5.8 (O)
unnamed: LCD_L.3, U$3.P$3 (3)
unnamed: LCD_H.7, R10.2
unnamed: PW_LED.K (C), R1.2
unnamed: IC5.3 (O), IC5.9 (I0)
unnamed: IC5.6 (O), IC5.10 (I1)
PB2: IC2.31 (PB2), LED.2
PB3: IC2.32 (PB3), LED.3
PB4: IC2.33 (PB4), LED.4
PB5: IC2.34 (PB5), LED.5
PB6: IC2.35 (PB6), LED.6
PB7: IC2.36 (PB7)
RD*: IC1.32 (RD), IC2.9 (RD), IC5.4 (I0), IC5.5 (I1), SL5.1
READY: IC1.35 (READY), R3.1, SL4.6
RS: IC2.37 (PC0), LCD_L.4
RST5.5: IC1.9 (RST5_5), R6.1, SL3.1, TIMER.2
RST6.5: IC1.8 (RST6_5), PIR.2, R7.1, SL2.8
RST7.5: IC1.7 (RST7_5), R8.1, R20.2, SL2.7, U$5.GPIO0
RST_IN: C3.2, IC1.36 (RES_IN), R2.1, RESET.3 (S), RESET.4 (S1), SL4.5
RST_OUT: IC1.3 (RES_OUT), IC2.4 (RESET), SL2.3
S0: IC1.29 (S0), SL5.4
S1: IC1.33 (S1), SL4.8
SID: IC1.5 (SID), R12.1, SL2.5, U$5.TX (TXD)
SOD: IC1.4 (SOD), R18.2, SL2.4, U$5.RX (RXD)
TIMER_OUT: IC2.6 (TIMEROUT), TIMER.1
TRAP: IC1.6 (TRAP), R9.1, SL2.6
VCC: C1.+, C2.1, C4.1, C5.1, C7.1, C8.1, C9.1, C11.1, IC1.40 (VCC), IC2.40 (VCC), IC3.20 (VCC), IC4.27 (!WE), IC4.28 (VCC), IC5.14 (VCC), IC6.3 (VIN), LCD_L.1, LED.1, PIR.3, POWER.2, PW_LED.A, R2.2, R3.2, SL4.1, U$2.VBUS (VCC), U$3.P$2 (2)
WR*: IC1.31 (WR), IC2.10 (WR), SL5.2
X1: C10.1, IC1.1 (X1), Q1.2, SL2.1
X2: C6.1, IC1.2 (X2), Q1.1, SL2.2

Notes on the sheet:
TITLE
8085 BASED SMART MIRROR
MANOJ SAHU & UDIT AGGARWAL
VERSION NO. 1
Power Supply
Decoder Circuit
LCD & LED Connector
Connectors
8085, ROM & 8155 (PPI)
Wi-Fi Module
PIR Connector

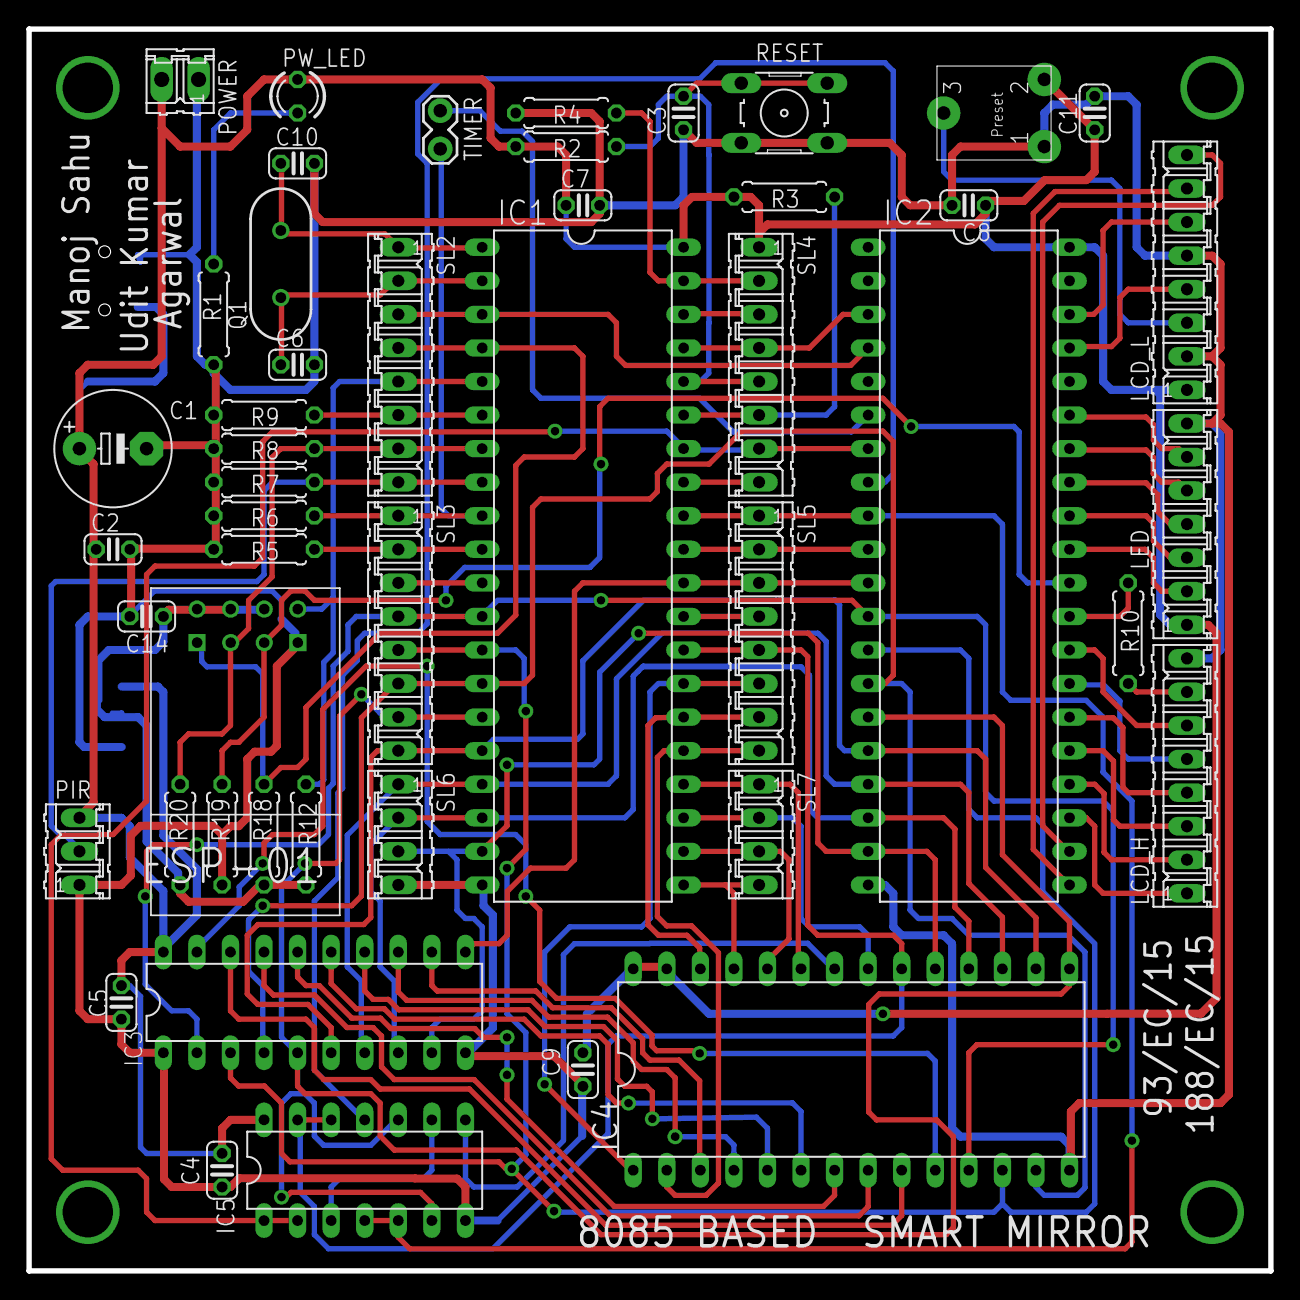
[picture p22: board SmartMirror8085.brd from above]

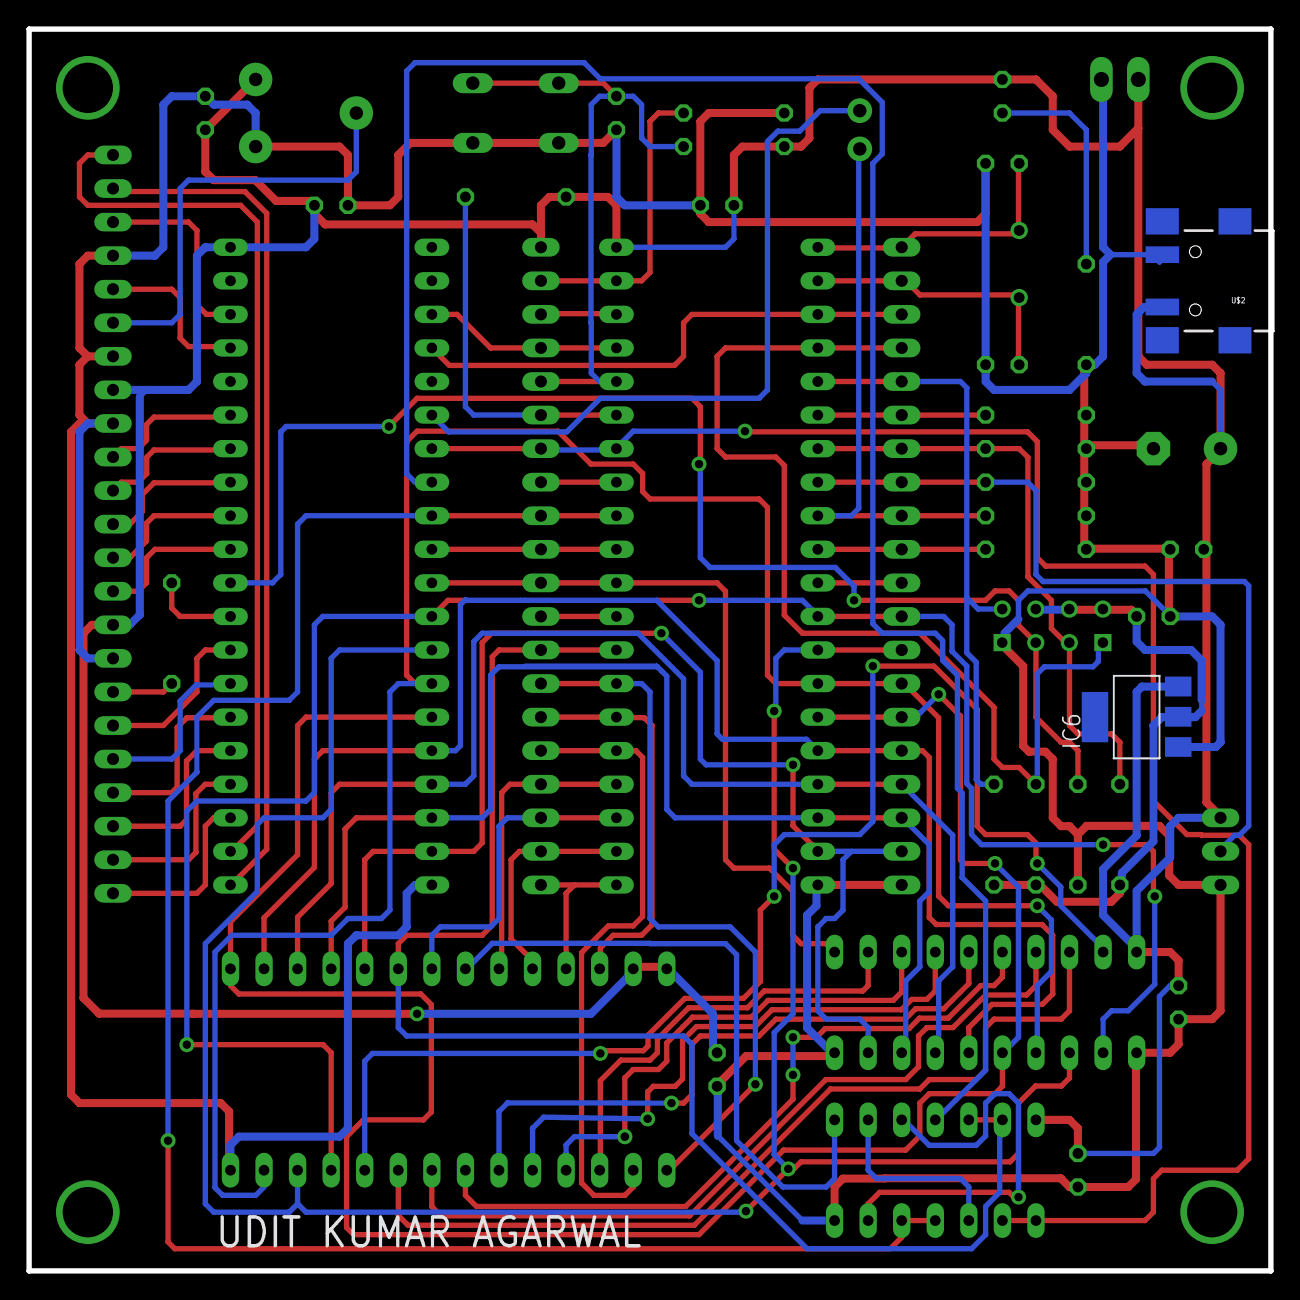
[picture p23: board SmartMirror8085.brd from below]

Board: 2 copper layers, 94.0 x 94.0 mm, 50 parts (2 on the bottom side), 74 nets.

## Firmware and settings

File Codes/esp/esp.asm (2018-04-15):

# SW_REG EQU 80H
# PORTA EQU 81H
# PORTB EQU 82H
# PORTC EQU 83H
# ORG 0000H
	   JMP MAIN
# ORG MAIN

MAIN:	   LXI SP,80FF	// STACK POINTER INITIALIZE
	   LXI H,1000	// MEMORY POINTER
	   CALL PPI_INIT	// INITIALIZE PPI FOR LCD
// ESP CODE
	   MVI E,00

LOOP:	   RIM
	   ANI 80
	   JNZ LOOP
	   MVI B,1D	// 150uSEC DELAY
	   CALL DELAY
	   RIM
	   ANI 80
	   MVI D,07	// 7 TIMES SHIFT RIGHT
	   CALL SHIFT
	   ORA E
	   MOV E,A
// YHA TK 1 BIT MIL GAI
	   MVI B,06
	   CALL DELAY
	   RIM
	   ANI 80
	   MVI D,06	// 6 TIMES SHIFT RIGHT
	   CALL SHIFT
	   ORA E
	   MOV E,A
// YHA TK 2 BIT MIL GAI
	   MVI B,06
	   CALL DELAY
	   RIM
	   ANI 80
	   MVI D,05	// 5 TIMES SHIFT RIGHT
	   CALL SHIFT
	   ORA E
	   MOV E,A
// YHA TK 3 BIT MIL GAI
	   MVI B,06
	   CALL DELAY
	   RIM
	   ANI 80
	   MVI D,04	// 4 TIMES SHIFT RIGHT
	   CALL SHIFT
	   ORA E
	   MOV E,A
// YHA TK 4 BIT MIL GAI
	   MVI B,06
	   CALL DELAY
	   RIM
	   ANI 80
	   MVI D,03	// 3 TIMES SHIFT RIGHT
	   CALL SHIFT
	   ORA E
	   MOV E,A
// YHA TK 5 BIT MIL GAI
	   MVI B,06
	   CALL DELAY
	   RIM
	   ANI 80
	   MVI D,02	// 2 TIMES SHIFT RIGHT
	   CALL SHIFT
	   ORA E
	   MOV E,A
// YHA TK 6 BIT MIL GAI
	   MVI B,06
	   CALL DELAY
	   RIM
	   ANI 80
	   MVI D,01	// 1 TIMES SHIFT RIGHT
	   CALL SHIFT
	   ORA E
	   MOV E,A
// YHA TK 7 BIT MIL GAI
	   MVI B,06
	   CALL DELAY
	   RIM
	   ANI 80	// ISME SHIFT NAHI HOGA
	   ORA E
	   MOV E,A
// YHA TK 8 BIT MIL GAI
	   STA 8001
	   CPI 41
	   MVI A,07
	   OUT PORTB
	   HLT

SHIFT:	   RRC
	   DCR D
	   JNZ SHIFT
	   RET

PPI_INIT:	   MVI A,0F	// PORTA,B,C OUTPUT MODE
	   OUT SW_REG
	   XRA A	// CLEAR ACCUMULATOR
	   OUT PORTA	// SET PORTA ZERO
	   OUT PORTC	// SET PORTC ZERO
	   MVI A,01
	   OUT PORTB	// BACKLIGHT ON
	   RET

DELAY:	   DCR B	// ARGUEMENT MUST BE PASSED IN B REG
	   JNZ DELAY
	   RET

LCD_INIT:	   MVI D,38	// DL - 2,FONT 5X7
	   CALL SEND_CMND
	   MVI D,0C	// DISPLAY ON,CURSOR OFF,BLINK OFF
	   CALL SEND_CMND
	   MVI D,06	// CURSOR INCREMENT
	   CALL SEND_CMND
	   RET

SEND_CMND:	   MOV A,D	// GET ARGUEMENT FROM D REGISTER
	   OUT PORTA
	   MVI A,02	// RS = 0, EN = 1
	   OUT PORTC
	   XRA A
	   OUT PORTC	// RS = 0, EN = 0
	   MVI B,03
	   CALL DELAY
	   RET

PRINTLOOP:	   MOV A,M	// FETCH DATA FROM MEMORY
	   OUT PORTA
	   MVI A,03	// RS = 1, EN = 1
	   OUT 83
	   MVI A,01	// RS = 1, EN = 0
	   OUT 83
	   MVI B,02
	   CALL DELAY	// DELAY FOR 30 uSEC
	   INX H	// INCREMENT MEM POINTER
	   DCR C
	   JNZ PRINTLOOP
	   RET
# ORG 1000H
# DB 38H,30H,38H,35H,42H,41H,53H,45H,44H,53H,4DH,41H,52H,54H,4DH,49H,52H,52H,4FH,52H

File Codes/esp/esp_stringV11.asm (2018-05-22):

// POINTER TO NUMBER OF CHARACTERS
# SW_REG EQU 80H
# PORTA EQU 81H
# PORTB EQU 82H
# PORTC EQU 83H
# ORG 0000H
	   JMP MAIN
# ORG 003CH
	   JMP RST7_5
# ORG 0500

MAIN:	   LXI SP,80FF	// STACK POINTER INITIALIZE
	   LXI H,8001	// MEMORY POINTER
	   MVI A,0B
	   SIM
	   CALL PPI_INIT	// INITIALIZE PPI FOR LCD
	   CALL BIG_DELAY
	   CALL LCD_INIT
	   EI

MAIN_LOOP:	   JMP MAIN_LOOP
	   HLT

PRINT:	   MVI D,01
	   CALL SEND_CMND
	   MVI B,FF
	   CALL DELAY
	   MOV D,C
	   MVI C,1A
	   LXI H,0A00
	   CALL PRINTLOOP
	   MOV C,D
	   MVI E,01
	   CALL CHANGELINE
	   LXI H,8001
	   CALL PRINTLOOP
	   RET

PPI_INIT:	   MVI A,0F	// PORTA,B,C OUTPUT MODE
	   OUT SW_REG
	   XRA A	// CLEAR ACCUMULATOR
	   OUT PORTA	// SET PORTA ZERO
	   OUT PORTC	// SET PORTC ZERO
	   MVI A,03
	   OUT PORTB	// BACKLIGHT ON
	   RET

DELAY:	   DCR B	// ARGUEMENT MUST BE PASSED IN B REG
	   JNZ DELAY
	   RET

LCD_INIT:	   MVI D,38	// DL - 2,FONT 5X7
	   CALL SEND_CMND
	   MVI D,01
	   CALL SEND_CMND
	   MVI B,FF
	   CALL DELAY
	   MVI B,2F
	   CALL DELAY
	   MVI D,0C	// DISPLAY ON,CURSOR OFF,BLINK OFF
	   CALL SEND_CMND
	   MVI D,06	// CURSOR INCREMENT
	   CALL SEND_CMND
	   LXI H,0C00
	   MVI C,04	// NO OF CHARACTERS '4'
	   CALL PRINTLOOP
	   MVI D,C4	// SECOND ROW 4 COLM
	   CALL SEND_CMND
	   MVI C,05
	   CALL PRINTLOOP
	   MVI D,9D	// THIRD ROW
	   CALL SEND_CMND
	   MVI C,05
	   CALL PRINTLOOP
	   MVI D,E2	// FOURTH ROW
	   CALL SEND_CMND
	   MVI C,06
	   CALL PRINTLOOP
	   RET

SEND_CMND:	   MOV A,D	// GET ARGUEMENT FROM D REGISTER
	   OUT PORTA
	   MVI A,02	// RS = 0, EN = 1
	   OUT PORTC
	   XRA A
	   OUT PORTC	// RS = 0, EN = 0
	   MVI B,2F
	   CALL DELAY
	   RET

PRINTANGLE:	   MVI A,3E	// RIGHT ANGLE BRACKET
	   OUT PORTA
	   MVI A,03	// RS = 1, EN = 1
	   OUT PORTC
	   MVI A,01	// RS = 1, EN = 0
	   OUT PORTC
	   MVI B,2D
	   CALL DELAY	// DELAY FOR 30 uSEC
// TAKE ACC AS PARAM
	   RET

CHANGELINE:	   INR E
	   MOV A,E
	   CPI 01
	   CZ FIRSTLINE
	   CPI 02
	   CZ SECONDLINE
	   CPI 03
	   CZ THIRDLINE
	   CPI 04
	   CZ FOURTHLINE
	   CALL PRINTANGLE
	   RET

FIRSTLINE:	   MVI D,80	// CURSOR MOVE TO FIRST LINE
	   CALL SEND_CMND
	   RET

SECONDLINE:	   MVI D,C0	// CURSOR MOVE TO SECOND LINE
	   CALL SEND_CMND
	   RET

THIRDLINE:	   MVI D,94	// CURSOR MOVE TO THIRD LINE
	   CALL SEND_CMND
	   RET

FOURTHLINE:	   MVI D,D4	// CURSOR MOVE TO FOURTH LINE
	   CALL SEND_CMND
	   RET

INCLINE:	   CALL CHANGELINE
	   JMP NEXTPRINT

PRINTLOOP:	   MOV A,M	// FETCH DATA FROM MEMORY
	   CPI 0A
	   JZ INCLINE
	   CPI 07
	   JZ WEATHER
	   OUT PORTA
	   MVI A,03	// RS = 1, EN = 1
	   OUT PORTC
	   MVI A,01	// RS = 1, EN = 0
	   OUT PORTC
	   MVI B,2F
	   CALL DELAY	// DELAY FOR 30 uSEC

NEXTPRINT:	   INX H	// INCREMENT MEM POINTER
	   DCR C
	   JNZ PRINTLOOP
	   MVI A,00
	   OUT PORTC
	   RET

RST7_5:	   PUSH B
	   PUSH PSW
	   PUSH D
	   PUSH H
	   LXI H,8001
	   MVI C,00

START_BIT:	   RIM	// CHECK FOR START BIT
	   ANI 80
	   JNZ START_BIT
	   MVI E,00
	   MVI D,07
	   MVI B,1C
	   CALL DELAY	// 150uSEC DELAY

BIT_READ:	   RIM
	   ANI 80
	   JNZ HIGH
	   XRA A	// LOW BIT

HIGH:	   ORA E
	   RRC
	   MOV E,A
	   XRA A	// JUST TO CONSUME EXTRA TIME
	   MVI B,10
	   CALL DELAY
	   DCR D	// BIT COUNTER
	   JNZ BIT_READ
	   RIM	// READS LAST BIT
	   ANI 80
	   ORA E
// ALL BITS RECIEVED
	   MOV E,A
	   CPI 09
	   JZ LOOPEXIT	// STOP RECIEVING IF WE GET '/t'
	   MOV M,E
	   INX H
	   INR C

STOP_BIT:	   RIM	// WAIT TILL STOP BIT RECIEVED
	   ANI 80
	   JZ STOP_BIT
	   JMP START_BIT

LOOPEXIT:	   CALL PRINT
	   MVI A,1B
	   SIM
	   MVI A,0B
	   SIM
	   POP H
	   POP D
	   POP PSW
	   POP B
	   EI
	   RET

BIG_DELAY:	   LXI B,0A2B

BIG_DELAYLOOP:	   DCX B
	   MOV A,B
	   ORA C
	   JNZ BIG_DELAYLOOP
	   RET

WEATHER:	   INX H
	   MOV A,M
	   SBI 30
	   MOV M,A
	   MVI A,01

INCR:	   RLC
	   DCR M
	   JNZ INCR
	   ORI 03
	   OUT PORTB
	   RET
# ORG 0A00H
# DB 80H,20H,20H,2AH,2AH,54H,6FH,2DH,44H,6FH,20H,4CH,69H,73H,74H,2AH,2AH,20H,20H,20H,20H,20H
# ORG 0C00H
# DB 38H,30H,38H,35H,42H,41H,53H,45H,44H,53H,4DH,41H,52H,54H,4DH,49H,52H,52H,4FH,52H

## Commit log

2018-04-03 Added schematic
    [188_93_EC_15.sch]
2018-04-15 Added design files and codes
    [SmartMirror8085.brd, SmartMirror8085.sch]
2019-10-01 Update README, Rearrange project files
    [188_93_EC_15.sch]

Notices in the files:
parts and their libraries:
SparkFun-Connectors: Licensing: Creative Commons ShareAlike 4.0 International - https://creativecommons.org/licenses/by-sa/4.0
